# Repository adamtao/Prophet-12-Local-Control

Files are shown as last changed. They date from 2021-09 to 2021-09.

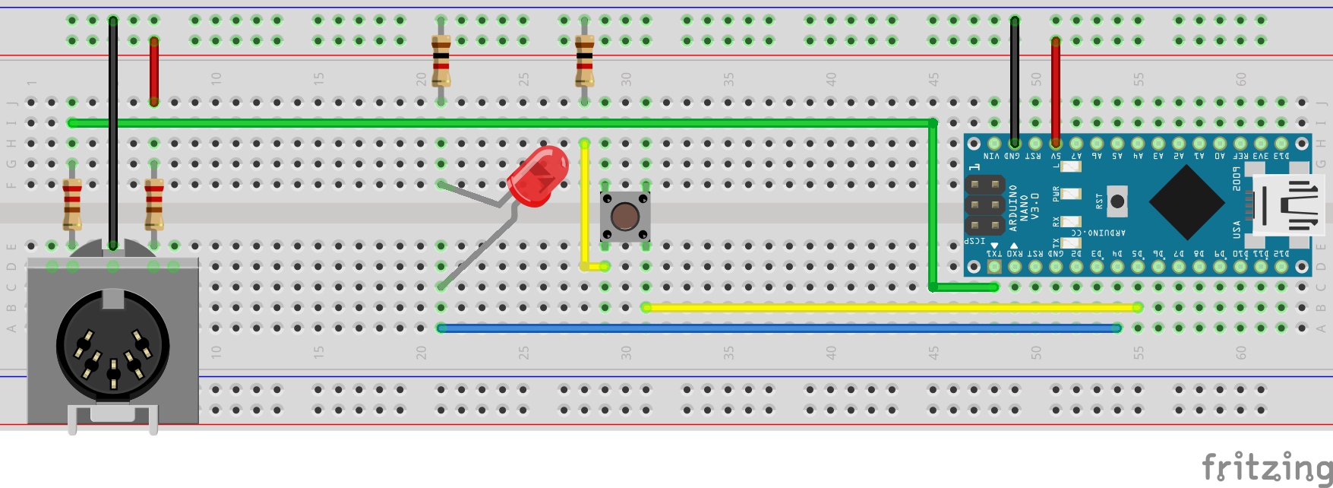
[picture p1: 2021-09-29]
Prophet 12 Button_bb.jpg

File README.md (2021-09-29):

# P12 Local Control Button

### Motivation

If you're like me, I use my DSI/Sequential Prophet 12 synthesizer a lot.
Lately I use it both as my primary MIDI controller and as a standalone
synth.

The synth has a setting in the "Global" menu to turn "Local Control"
on or off. Generally, I like having Local Control turned ON when using
it as a synth. It's just a nicer experience to have all of the controls
function as expected.

When using it as a MIDI controller with my DAW, I turn Local Control OFF.

Well, this tends to get tedious using the Global menu to toggle the two
modes. I've memorized the setting as item 15 in the menu to scroll to.
So, rather than going to Global, scrolling 15 items down, then toggling
the setting, I've made an external button to toggle it.

I decided to use up the Prophet's MIDI IN jack for this project since
I had previously only been using the USB MIDI. Sure, it's kind of a
waste of a MIDI input for a single button, but hey I like it.

## Code Notes

The code here is an Arduino sketch to send the P12 NRPN command which
corresponds to Local Control (1035). Some of the other Prophets of
the same era use the same NRPN, so this should also work for the OB6
and Prophet 6, and maybe others.

You'll notice the code depends on a few libraries. The Arduino IDE should
help you locate and install them if you don't have them already:

* EEPROM
* [MIDI](https://github.com/FortySevenEffects/arduino_midi_library)
* [EasyButton](https://github.com/evert-arias/EasyButton)

### The Circuit

The circuit consists of a momentary button, a convenience LED, a few
resistors, MIDI connector and an Arduino. In my case I used an Arduino
Nano, but others should work, too.

I've included some JPGs showing off my rudimentary skills in making a
schematic and a breadboard layout. Prepare to be impressed, but do
double-check everything. I put this together _after_ I made my device.

### MIDI Channel Configuration

By default, the device sends the message on MIDI channel 12. To change
that, alter the code, or follow this sequence after building the
device:

1. Press and hold the button, observe 3 LED flashes
2. Press the button again several times. The number of times you press will be the new MIDI channel.
3. Press and hold the button, observe 3 LED flashes

Now the new channel is stored in EEPROM.

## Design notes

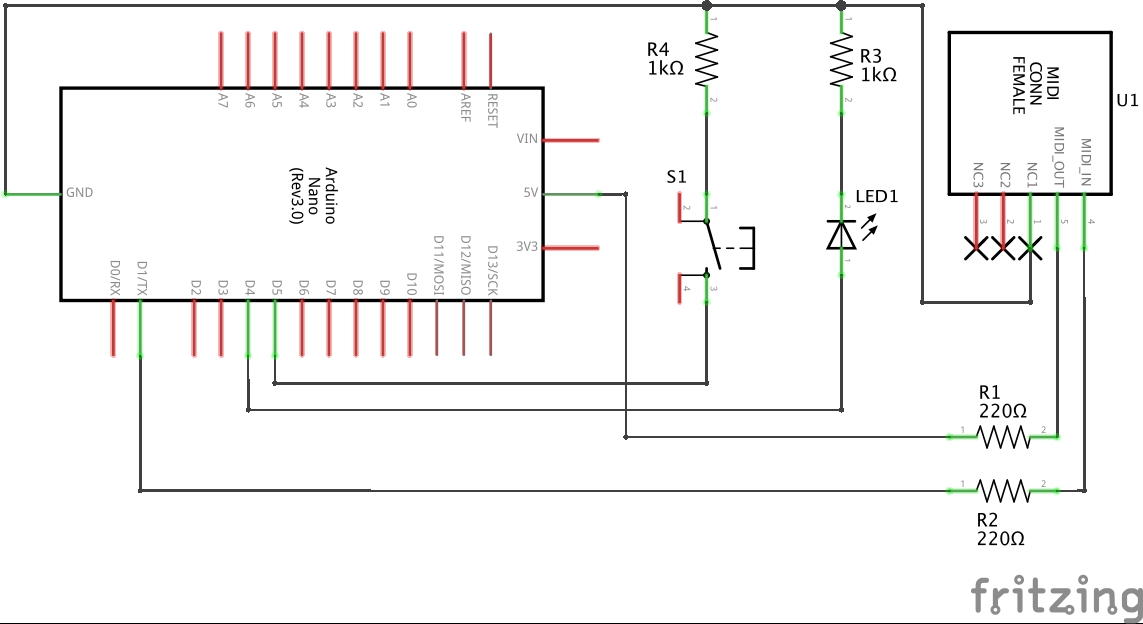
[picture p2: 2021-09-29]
Prophet 12 Button_schem.jpg

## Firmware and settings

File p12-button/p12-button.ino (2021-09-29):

#include <EEPROM.h>
#include <MIDI.h>
#include <EasyButton.h>

/*
 * Nifty 1-button to toggle "Local Control" on a Prophet 12 synthesizer. This
 * is handy so you can quickly go back and forth between using the Prophet as
 * a MIDI controller (with local control off) vs. a synth (with local control
 * on).
 * 
 * There are two modes: Normal mode and Setup mode.
 * 
 * Normal mode lets you use a momentary button on pin 5 to toggle the local
 * control of the Prophet 12. This device starts up without knowing the state
 * of the Prophet, so the first press turns ON local control. Each press after
 * that toggles local control on/off. The LED on pin 4 lights up when local
 * control is ON.
 * 
 * Setup mode is accessed by pressing and holding the button for 2 sec. You'll
 * see 3 quick blinks of the LED. Now you can set the MIDI channel by pressing
 * the button several times. Count 1, 2, 3... as you press the button until 
 * you get to the desired MIDI channel number. Then press and hold the button
 * for 2 sec. to exit setup mode. The new MIDI channel is stored in memory so
 * the next time you turn on the device, it will remember that channel.
 * 
 * (The default MIDI channel on a fresh device is 12.)
 * 
 * Hooking it up: (how I did it at least)
 * 
 * Arduino pin 5 -> momentary button
 * other leg of momentary button -> 1k resistor -> ground
 * 
 * Arduino pin 4 -> LED (+)
 * LED (-) -> 1k resistor -> ground
 * 
 * Arduino pin 2 (TX) -> 220 ohm resistor -> MIDI jack pin 5
 * MIDI jack pin 2 -> ground
 * MIDI jack pin 4 -> 220 ohm resistor -> +5v
 * 
 * MIDI cable from this device to MIDI In on Prophet 12
 * 
 * NOTE: You'll need to disconnect pin 2 (TX) on the Arduino while uploading
 * the code to the Arduino.
 */

#define DEFAULT_MIDI_CHANNEL 12
#define LED 4
#define BUTTON 5


MIDI_CREATE_DEFAULT_INSTANCE();
EasyButton toggle_button(BUTTON);

boolean local_control = false;
boolean setup_mode = false;
int midi_channel = DEFAULT_MIDI_CHANNEL;
int new_midi_channel = 0;
int address = 0;

void setup() {
  MIDI.begin(MIDI_CHANNEL_OFF);

  pinMode(LED, OUTPUT);
  digitalWrite(LED, LOW);

  // Read stored MIDI channel from memory
  int stored_midi_channel = EEPROM.read(address);
  if (stored_midi_channel > 0 && stored_midi_channel <= 16) {
    midi_channel = stored_midi_channel;
  }

  toggle_button.begin();
  toggle_button.onPressed(perform_button_function);
  toggle_button.onPressedFor(2000, toggle_setup_mode);
}

void loop() {
  toggle_button.read();
}

void perform_button_function() {
  if (setup_mode == true) {
    increment_midi_channel();
  } else {
    toggle_local_control();
  }
}

void toggle_local_control() {
  MIDI.beginNrpn(1035, midi_channel);
  MIDI.sendNrpnValue(0, local_control ? 0 : 1, midi_channel);
  MIDI.endNrpn(midi_channel);
  digitalWrite(LED, local_control ? LOW : HIGH);
  local_control = !local_control;
}

void toggle_setup_mode() {
  setup_mode = !setup_mode;
  new_midi_channel = 0;
  blink(3);
  if (setup_mode == false && local_control == true) {
    digitalWrite(LED, HIGH); // return to LED state before setup mode
  }
}

void increment_midi_channel() {
  if (new_midi_channel < 16) {
    new_midi_channel += 1;
    EEPROM.write(address, new_midi_channel);
    midi_channel = new_midi_channel;
    digitalWrite(LED, HIGH);
    delay(50);
    digitalWrite(LED, LOW);
  }
}

void blink(int count) {
  while(count > 0) {
    digitalWrite(LED, HIGH);
    delay(100);
    digitalWrite(LED, LOW);
    delay(100);
    count -= 1;
  }
}
